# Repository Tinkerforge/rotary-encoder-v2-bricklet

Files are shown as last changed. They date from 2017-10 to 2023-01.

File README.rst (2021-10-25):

Rotary Encoder Bricklet 2.0
===========================

This repository contains the firmware source code and the hardware design
files. The documentation generator configs can be found at
https://github.com/Tinkerforge/generators

Repository Content
------------------

software/:
 * examples/: Examples for all supported languages
 * build/: Compiled files
 * src/: Source code of firmware
 * Makefile: Makefile to build project

hardware/:
 * Contains KiCad project files and additionally schematics as PDF

datasheets/:
 * Contains datasheets for sensors and complex ICs that are used

Hardware
--------

The hardware is designed with the open source EDA Suite KiCad
(http://www.kicad.org). Before you are able to open the files,
you have to install the Tinkerforge kicad-libraries
(https://github.com/Tinkerforge/kicad-libraries). You can either clone
them directly in hardware/ or clone them in a separate folder and
symlink them into hardware/
(ln -s kicad_path/kicad-libraries project_path/hardware). After that you
can open the .pro file in hardware/ with KiCad and from there view and
modify the schematics and the PCB layout.

Software
--------

If you want to do your own Brick/Bricklet firmware development we highly
recommend that you use our build environment setup script and read the
tutorial (https://www.tinkerforge.com/en/doc/Tutorials/Tutorial_Build_Environment/Tutorial.html).

To compile the C code we recommend you to install the newest GNU Arm Embedded
Toolchain (https://launchpad.net/gcc-arm-embedded/+download).
You also need to install bricklib2 (https://github.com/Tinkerforge/bricklib2).

You can either clone it directly in software/src/ or clone it in a
separate folder and symlink it into software/src/
(ln -s bricklib_path/bricklib2 project_path/software/src/). Finally make sure to
have CMake installed (http://www.cmake.org/cmake/resources/software.html).

After that you can build the firmware by invoking make in software/.
The firmware (.zbin) can then be found in software/build/ and uploaded
with brickv (click button "Flashing" on start screen).

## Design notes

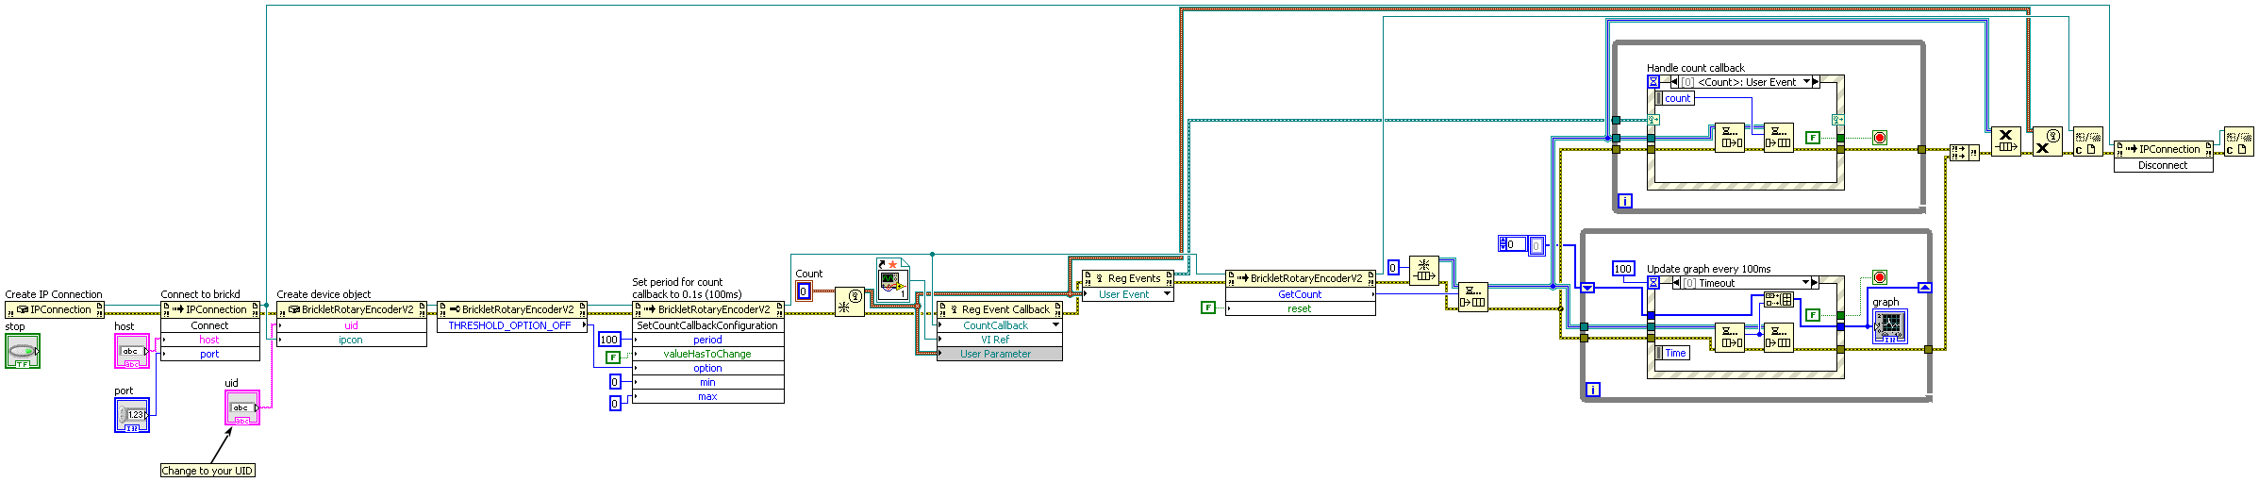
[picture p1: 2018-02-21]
software/examples/labview/Example Graph.vi.png

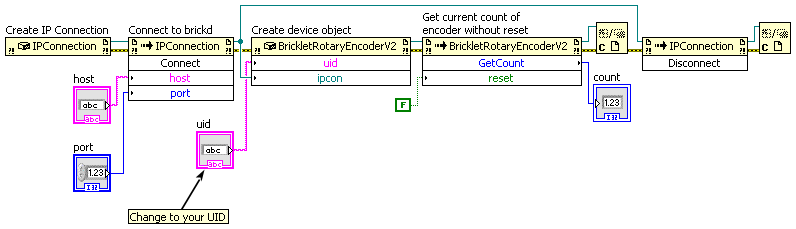
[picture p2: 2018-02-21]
software/examples/labview/Example Simple.vi.png

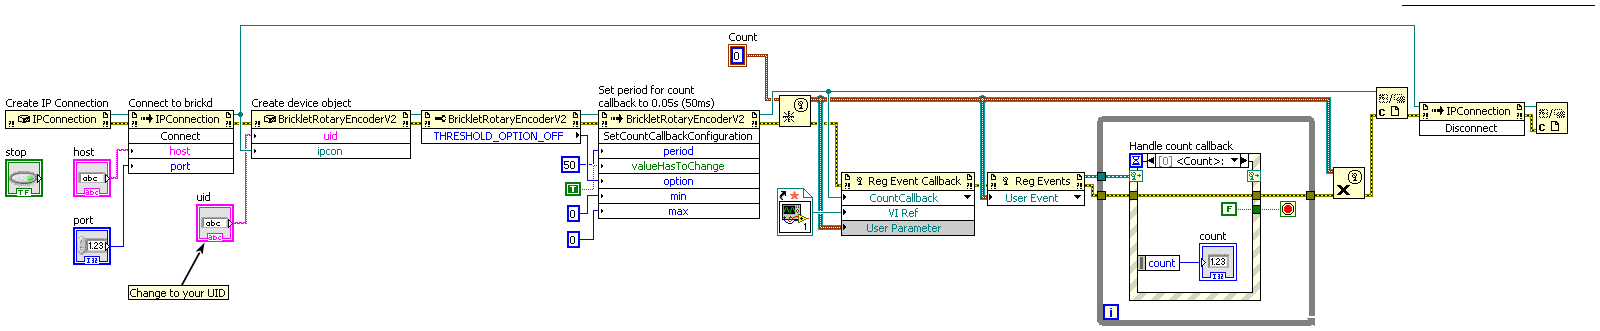
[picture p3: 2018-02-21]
software/examples/labview/Example Callback.vi.png

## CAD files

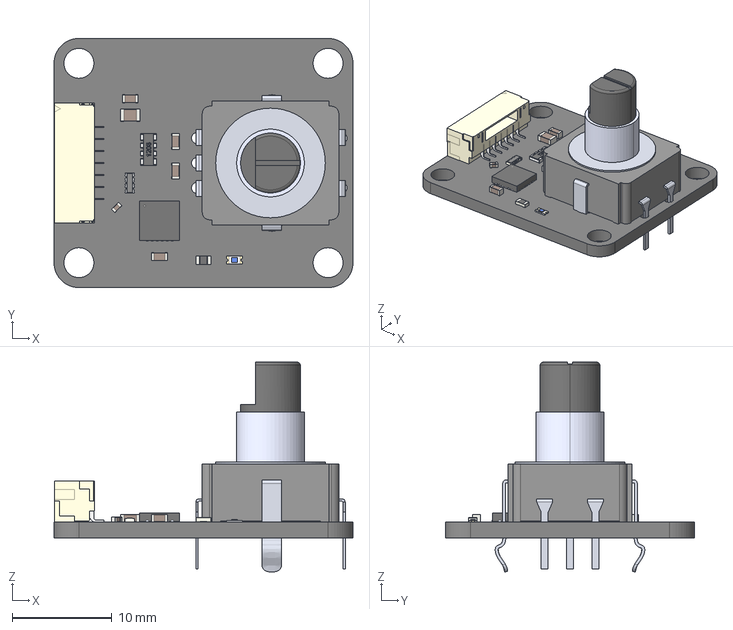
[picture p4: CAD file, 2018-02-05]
hardware/rotary-encoder-v2.step
30.0 x 25.0 x 21.0 mm

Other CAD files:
hardware/rotary-encoder-v2.FCStd

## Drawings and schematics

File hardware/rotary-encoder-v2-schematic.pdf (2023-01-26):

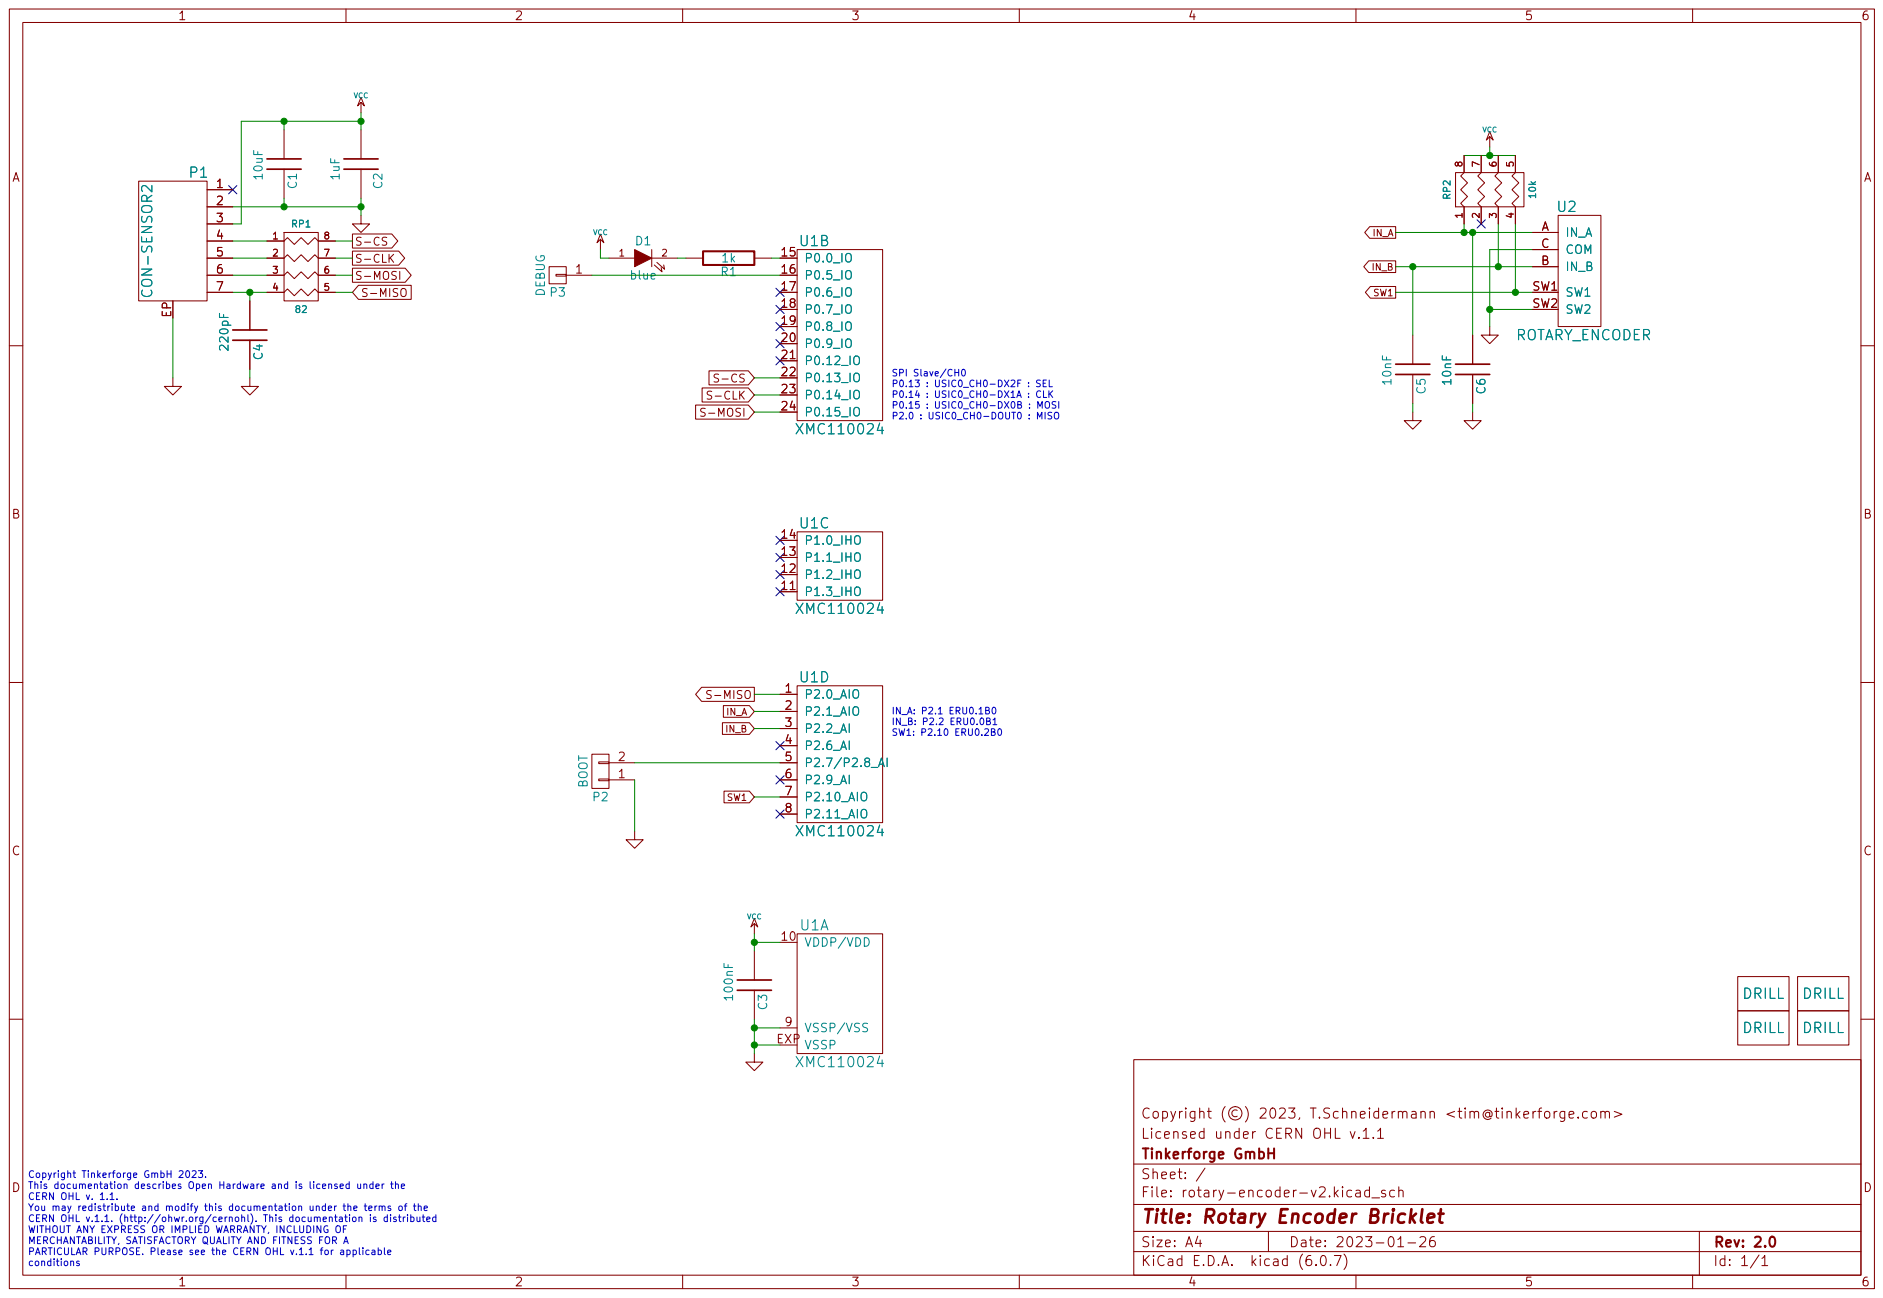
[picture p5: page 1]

SPI Slave/CH0 P0.13 : USIC0_CH0-DX2F : SEL P0.14 : USIC0_CH0-DX1A : CLK

IN_B: P2.2 ERU0.0B1 SW1: P2.10 ERU0.2B0 Copyright Tinkerforge GmbH 2023. This documentation describes Open Hardware and is licensed under the CERN OHL v. 1.1. You may redistribute and modify this documentation under the terms of the CERN OHL v.1.1. (http://ohwr.org/cernohl). This documentation is distributed WITHOUT ANY EXPRESS OR IMPLIED WARRANTY, INCLUDING OF MERCHANTABILITY, SATISFACTORY QUALITY AND FITNESS FOR A

Licensed under CERN OHL v.1.1
File: rotary-encoder-v2.kicad_sch Sheet: / Tinkerforge GmbH

Id: 1/1 Title: Rotary Encoder Bricklet

PARTICULAR PURPOSE. Please see the CERN OHL v.1.1 for applicable
conditions

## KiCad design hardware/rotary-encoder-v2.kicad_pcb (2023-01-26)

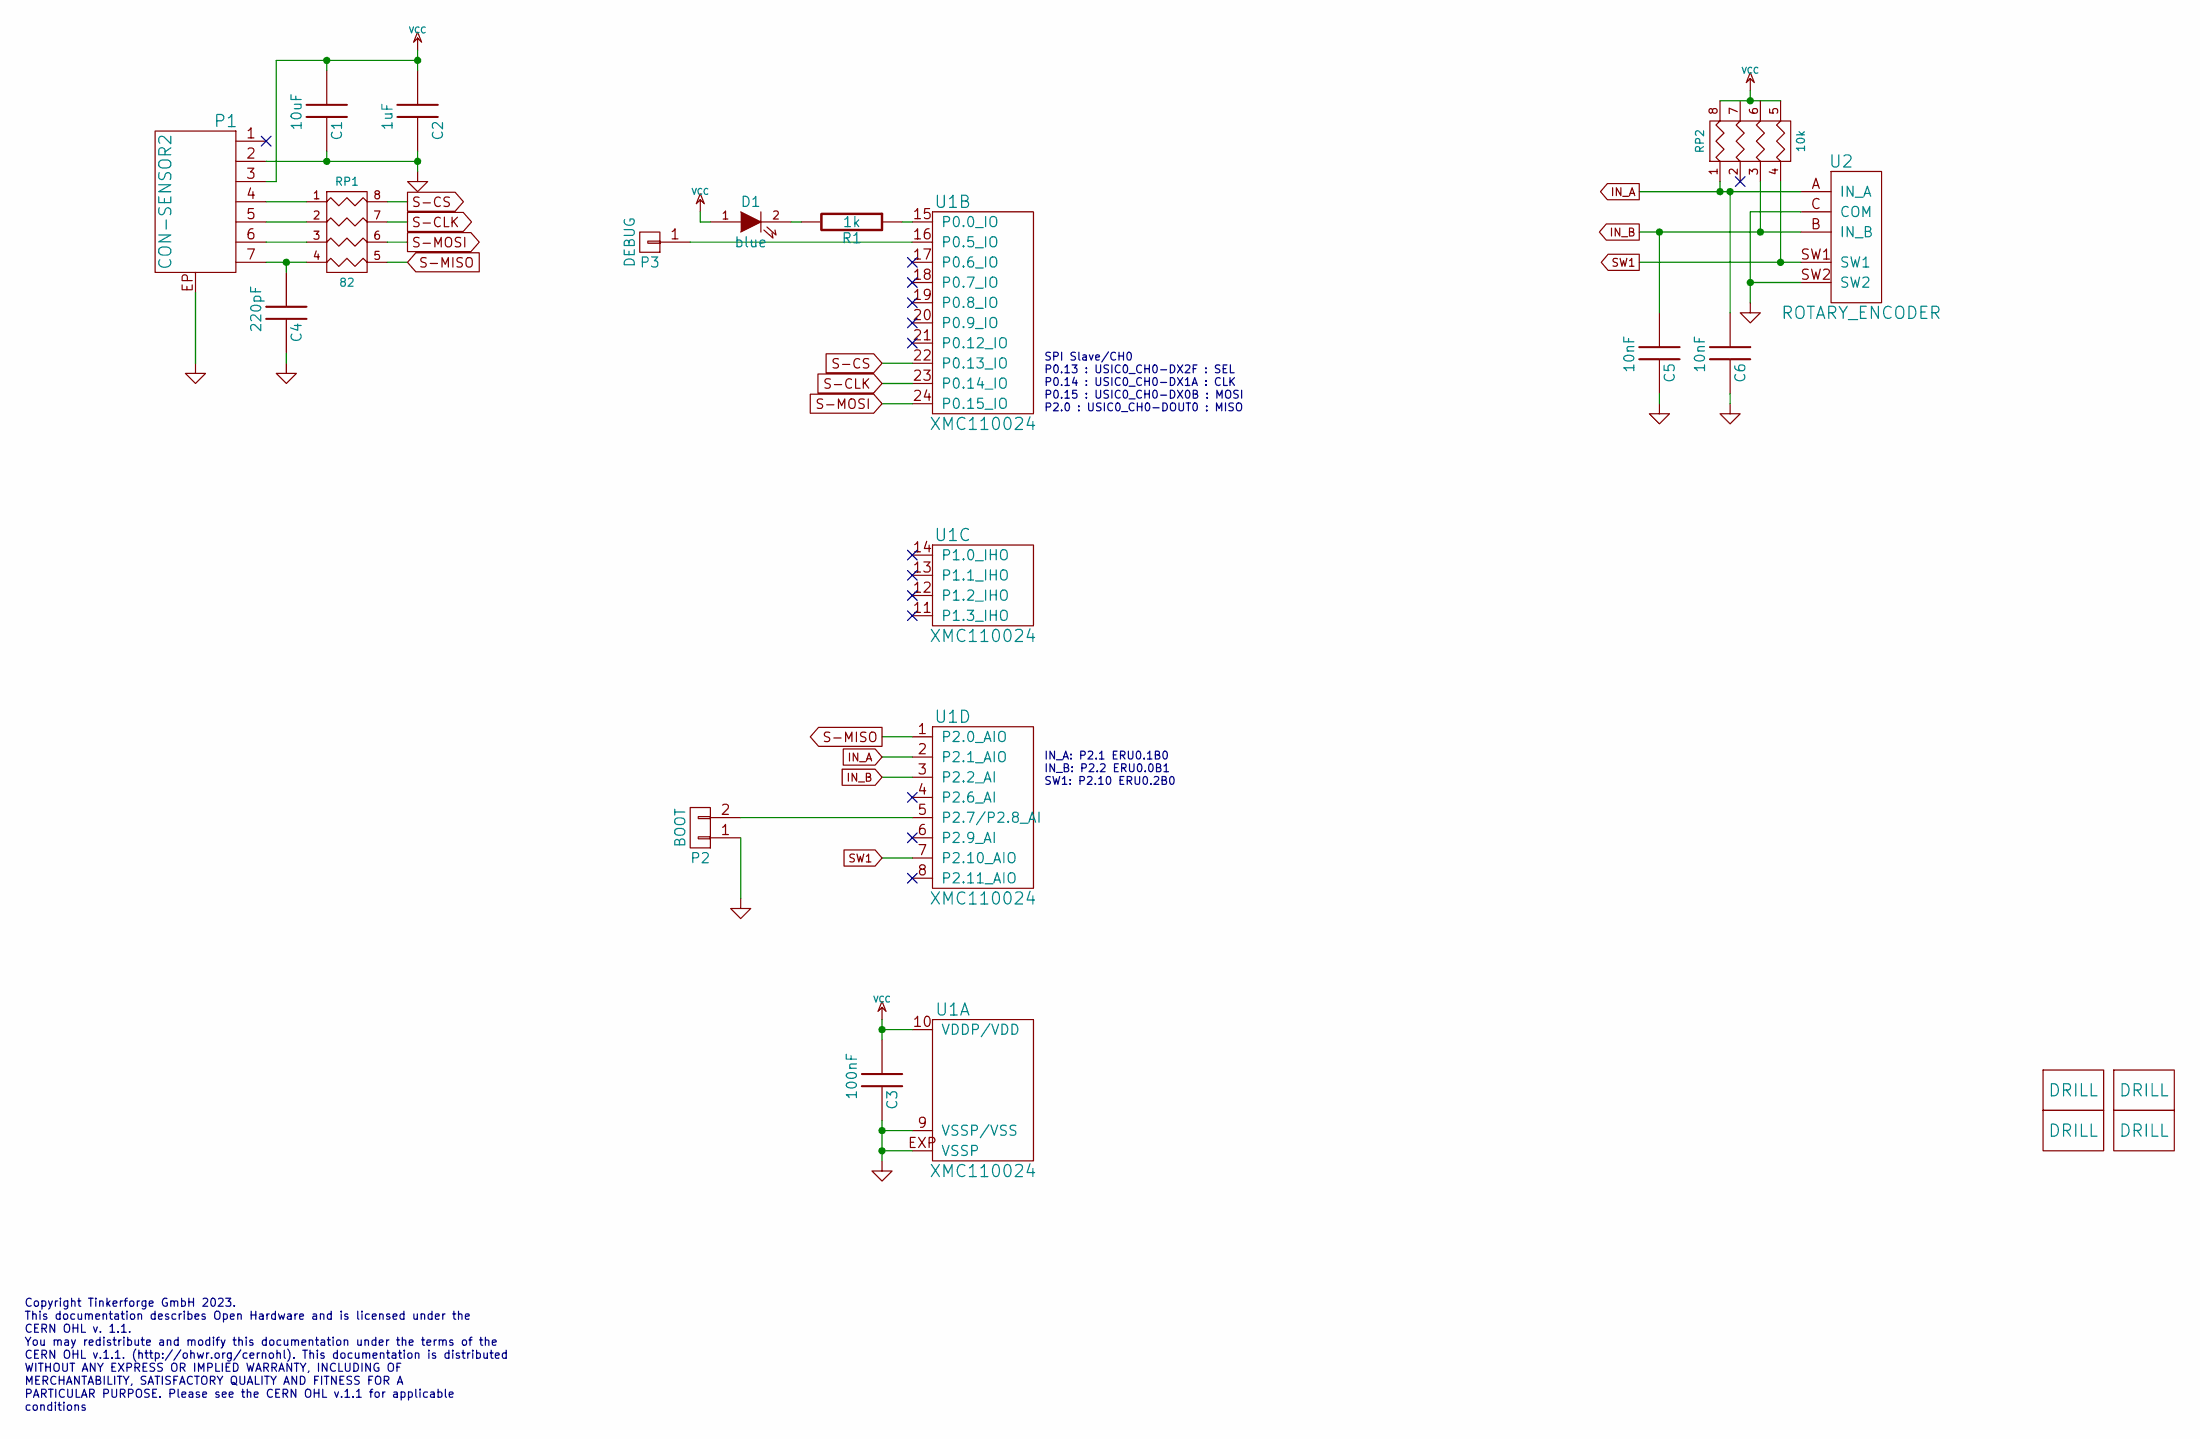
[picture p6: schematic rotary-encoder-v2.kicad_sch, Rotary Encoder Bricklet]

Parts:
C1: 10uF; C0805E
C2: 1uF; C0603F
C3: 100nF; C0603F
C4: 220pF; C0402F
C5, C6: 10nF; C0603F
D1: blue; D0603F
P1: CON-SENSOR2
P2: BOOT; SolderJumper
P3: DEBUG; DEBUG_PAD
R1: 1k; R0603F
RP1: 82; 4X0402
RP2: 10k; 4X0603
U1: XMC110024; QFN24-4x4mm-0.5mm
U2: ROTARY_ENCODER
U3, U4, U5, U6: DRILL; DRILL_NP

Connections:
GND: C1.2, C2.2, C3.2, C4.2, C5.2, C6.2, P1.2, P1.EP, P2.1, U1.9 (VSSP/VSS), U1.EXP (VSSP), U2.C (COM), U2.SW2
IN_A: C6.1, RP2.1, U1.2 (P2.1_AIO), U2.A (IN_A)
IN_B: C5.1, RP2.3, U1.3 (P2.2_AI), U2.B (IN_B)
unnamed: C4.1, P1.7, RP1.4
unnamed: D1.2 (K), R1.2
unnamed: P1.4, RP1.1
unnamed: P1.5, RP1.2
unnamed: P1.6, RP1.3
unnamed: P2.2, U1.5 (P2.7/P2.8_AI)
unnamed: P3.1, U1.16 (P0.5_IO)
unnamed: R1.1, U1.15 (P0.0_IO)
S-CLK: RP1.7 (R2), U1.23 (P0.14_IO)
S-CS: RP1.8 (R1), U1.22 (P0.13_IO)
S-MISO: RP1.5 (R4), U1.1 (P2.0_AIO)
S-MOSI: RP1.6 (R3), U1.24 (P0.15_IO)
SW1: RP2.4, U1.7 (P2.10_AIO), U2.SW1
VCC: C1.1, C2.1, C3.1, D1.1 (A), P1.3, RP2.5 (R4), RP2.6 (R3), RP2.7 (R2), RP2.8 (R1), U1.10 (VDDP/VDD)

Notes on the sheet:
IN_A: P2.1 ERU0.1B0 IN_B: P2.2 ERU0.0B1 SW1: P2.10 ERU0.2B0
Copyright Tinkerforge GmbH 2023. This documentation describes Open Hardware and is licensed under the CERN OHL v. 1.1. You may redistribute and modify this documentation under the terms of the CERN OHL v.1.1. (http://ohwr.org/cernohl). This documentation is distributed WITHOUT ANY EXPRESS OR IMPLIE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
SPI Slave/CH0 P0.13 : USIC0_CH0-DX2F : SEL P0.14 : USIC0_CH0-DX1A : CLK P0.15 : USIC0_CH0-DX0B : MOSI P2.0 : USIC0_CH0-DOUT0 : MISO

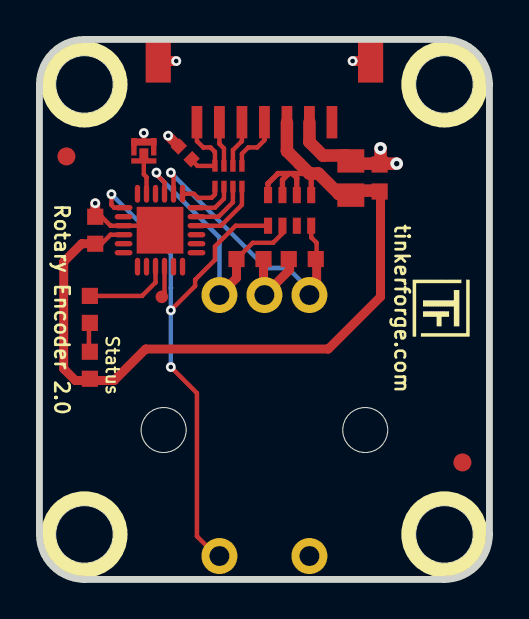
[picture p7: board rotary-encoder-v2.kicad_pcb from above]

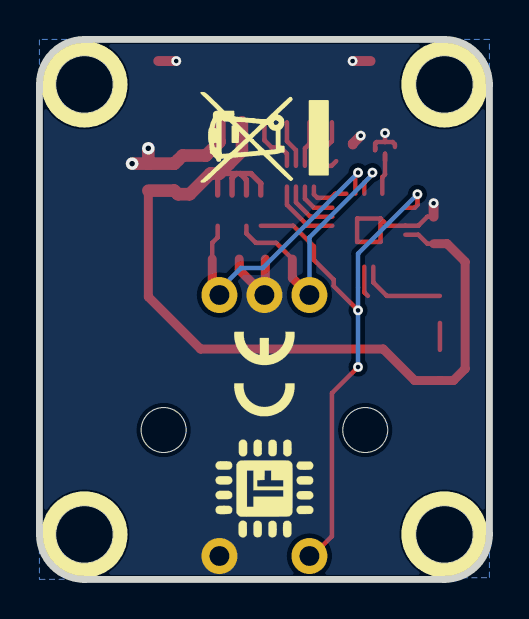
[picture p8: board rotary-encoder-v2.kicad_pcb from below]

Board: 2 copper layers, 25.0 x 30.0 mm, 23 parts (2 on the bottom side), 17 nets.

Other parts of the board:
Fiducial_Mark: VAL**; Fiducial_Mark
Fiducial_Mark#2: VAL**; Fiducial_Mark
VAL: WEEE_7mm
VAL#2: CE_5mm

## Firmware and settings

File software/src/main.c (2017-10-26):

/* rotary-encoder-v2-bricklet
 * Copyright (C) 2017 Olaf Lüke <olaf@tinkerforge.com>
 *
 * main.c: Initialization for Rotary Encoder V2 Bricklet
 *
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
 * You should have received a copy of the GNU Lesser General Public
 * License along with this library; if not, write to the
 * Free Software Foundation, Inc., 59 Temple Place - Suite 330,
 * Boston, MA 02111-1307, USA.
 */

#include <stdio.h>
#include <stdbool.h>

#include "configs/config.h"

#include "bricklib2/bootloader/bootloader.h"
#include "bricklib2/hal/system_timer/system_timer.h"
#include "bricklib2/logging/logging.h"
#include "communication.h"
#include "encoder.h"

int main(void) {
	logging_init();
	logd("Start Rotary Encoder V2 Bricklet\n\r");

	communication_init();
	encoder_init();

	while(true) {
		bootloader_tick();
		communication_tick();
		encoder_tick();
	}
}

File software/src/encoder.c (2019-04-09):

/* rotary-encoder-v2-bricklet
 * Copyright (C) 2017 Olaf Lüke <olaf@tinkerforge.com>
 *
 * encoder.c: Driver for rotary encoder
 *
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
 * You should have received a copy of the GNU Lesser General Public
 * License along with this library; if not, write to the
 * Free Software Foundation, Inc., 59 Temple Place - Suite 330,
 * Boston, MA 02111-1307, USA.
 */

#include "encoder.h"

#include <string.h>

#include "bricklib2/hal/system_timer/system_timer.h"

#include "configs/config.h"
#include "configs/config_encoder.h"

#include "xmc_eru.h"
#include "xmc_gpio.h"
#include "xmc_ccu4.h"

#define encoder_debounce_a_handler IRQ_Hdlr_21
#define encoder_debounce_b_handler IRQ_Hdlr_22

#define encoder_a_handler IRQ_Hdlr_4
#define encoder_b_handler IRQ_Hdlr_3

const int8_t encoder_table[4][4] = {
    { 0,  1, -1,  0},
    {-1,  0,  0,  1},
    { 1,  0,  0, -1},
    { 0, -1,  1,  0}
};

Encoder encoder;

static int32_t encoder_count = 0;
static int8_t encoder_last_value = 0;

// We do the actual measurements in the debounce handler.
// The handler is called 100us after we see a edge change.
// This way we make sure that we never take a value during the initial bounciness after the edge changes.
// If the pot is turned at "maximum human speed" the edges chage about every 500us, so with 100us debounce
// we still have a big margin of error.
void __attribute__((optimize("-O3"))) __attribute__ ((section (".ram_code"))) encoder_debounce_a_handler(void) {
	NVIC_ClearPendingIRQ(ENCODER_A_IRQ_N);
	NVIC_EnableIRQ(ENCODER_A_IRQ_N);

	const uint8_t encoder_value = XMC_GPIO_GetInput(ENCODER_A_PIN) | (XMC_GPIO_GetInput(ENCODER_B_PIN) << 1);

	int8_t add = encoder_table[encoder_last_value][encoder_value];
	encoder_count += add;
	encoder_last_value = encoder_value;
}

void __attribute__((optimize("-O3"))) __attribute__ ((section (".ram_code"))) encoder_debounce_b_handler(void) {
	NVIC_ClearPendingIRQ(ENCODER_B_IRQ_N);
	NVIC_EnableIRQ(ENCODER_B_IRQ_N);

	const uint8_t encoder_value = XMC_GPIO_GetInput(ENCODER_A_PIN) | (XMC_GPIO_GetInput(ENCODER_B_PIN) << 1);

	int8_t add = encoder_table[encoder_last_value][encoder_value];
	encoder_count += add;
	encoder_last_value = encoder_value;
}


void __attribute__((optimize("-O3"))) __attribute__ ((section (".ram_code"))) encoder_a_handler(void) {
	CCU40_CC40->TCCLR = CCU4_CC4_TCCLR_TCC_Msk;
	CCU40_CC40->TCSET = CCU4_CC4_TCSET_TRBS_Msk;
	NVIC_DisableIRQ(ENCODER_A_IRQ_N);
}

void __attribute__((optimize("-O3"))) __attribute__ ((section (".ram_code"))) encoder_b_handler(void) {
	CCU40_CC41->TCCLR = CCU4_CC4_TCCLR_TCC_Msk;
	CCU40_CC41->TCSET = CCU4_CC4_TCSET_TRBS_Msk;
	NVIC_DisableIRQ(ENCODER_B_IRQ_N);
}

void encoder_init_debounce_timer(void) {
	XMC_CCU4_SLICE_COMPARE_CONFIG_t timer_config = {
		.timer_mode          = XMC_CCU4_SLICE_TIMER_COUNT_MODE_EA,
		.monoshot            = XMC_CCU4_SLICE_TIMER_REPEAT_MODE_SINGLE,
		.shadow_xfer_clear   = false,
		.dither_timer_period = false,
		.dither_duty_cycle   = false,
		.prescaler_mode      = XMC_CCU4_SLICE_PRESCALER_MODE_NORMAL,
		.mcm_enable          = false,
		.prescaler_initval   = XMC_CCU4_SLICE_PRESCALER_64, // Use prescaler 64 to get 1 tick = 1us
		.float_limit         = 0U,
		.dither_limit        = 0U,
		.passive_level       = XMC_CCU4_SLICE_OUTPUT_PASSIVE_LEVEL_LOW,
		.timer_concatenation = false
	};

    XMC_CCU4_Init(CCU40, XMC_CCU4_SLICE_MCMS_ACTION_TRANSFER_PR_CR);
    XMC_CCU4_StartPrescaler(CCU40);


	// Timer input A
    XMC_CCU4_EnableClock(CCU40, 0);
    XMC_CCU4_SLICE_CompareInit(CCU40_CC40, &timer_config);
    XMC_CCU4_SLICE_SetTimerPeriodMatch(CCU40_CC40, ENCODER_DEBOUNCE_TIME);
    XMC_CCU4_SLICE_SetTimerCompareMatch(CCU40_CC40, 0);
    XMC_CCU4_EnableShadowTransfer(CCU40, XMC_CCU4_SHADOW_TRANSFER_SLICE_0 | XMC_CCU4_SHADOW_TRANSFER_PRESCALER_SLICE_0);

    XMC_CCU4_SLICE_EnableEvent(CCU40_CC40, XMC_CCU4_SLICE_IRQ_ID_PERIOD_MATCH);
	XMC_CCU4_SLICE_SetInterruptNode(CCU40_CC40, XMC_CCU4_SLICE_IRQ_ID_PERIOD_MATCH, XMC_CCU4_SLICE_SR_ID_0);
	NVIC_EnableIRQ(CCU40_0_IRQn);
	NVIC_SetPriority(CCU40_0_IRQn, ENCODER_DEBOUNCE_PRIO);


	// Timer input B
    XMC_CCU4_EnableClock(CCU40, 1);
    XMC_CCU4_SLICE_CompareInit(CCU40_CC41, &timer_config);
    XMC_CCU4_SLICE_SetTimerPeriodMatch(CCU40_CC41, ENCODER_DEBOUNCE_TIME);
    XMC_CCU4_SLICE_SetTimerCompareMatch(CCU40_CC41, 0);
    XMC_CCU4_EnableShadowTransfer(CCU40, XMC_CCU4_SHADOW_TRANSFER_SLICE_1 | XMC_CCU4_SHADOW_TRANSFER_PRESCALER_SLICE_1);

    XMC_CCU4_SLICE_EnableEvent(CCU40_CC41, XMC_CCU4_SLICE_IRQ_ID_PERIOD_MATCH);
	XMC_CCU4_SLICE_SetInterruptNode(CCU40_CC41, XMC_CCU4_SLICE_IRQ_ID_PERIOD_MATCH, XMC_CCU4_SLICE_SR_ID_1);
	NVIC_EnableIRQ(CCU40_1_IRQn);
	NVIC_SetPriority(CCU40_1_IRQn, ENCODER_DEBOUNCE_PRIO);
}

void encoder_init_eru(void) {
	// A config (ERU0.1B0)
	const XMC_ERU_ETL_CONFIG_t a_etl_config = {
		.input_a                = XMC_ERU_ETL_INPUT_A0,
		.input_b                = XMC_ERU_ETL_INPUT_B0,
		.enable_output_trigger  = 1,
		.edge_detection         = XMC_ERU_ETL_EDGE_DETECTION_BOTH,
		.output_trigger_channel = XMC_ERU_ETL_OUTPUT_TRIGGER_CHANNEL1, // Select the source for event
		.source                 = XMC_ERU_ETL_SOURCE_B
	};

	// ERU Event Trigger Logic Hardware initialization based on UI
	XMC_ERU_ETL_Init(XMC_ERU0, ENCODER_A_ETL_CHANNEL, &a_etl_config);
	// OGU is configured to generate event on configured trigger edge
	XMC_ERU_OGU_SetServiceRequestMode(XMC_ERU0, ENCODER_A_OGU_CHANNEL, XMC_ERU_OGU_SERVICE_REQUEST_ON_TRIGGER);
	// Configure NVIC node and priority
	NVIC_SetPriority(ENCODER_A_IRQ_N, ENCODER_A_IRQ_PRIO);

	// Clear pending interrupt before enabling it
	NVIC_ClearPendingIRQ(ENCODER_A_IRQ_N);
	// Enable NVIC node
	NVIC_EnableIRQ(ENCODER_A_IRQ_N);


	// B config (ERU0.0B1)
	const XMC_ERU_ETL_CONFIG_t b_etl_config = {
		.input_a                = XMC_ERU_ETL_INPUT_A0,
		.input_b                = XMC_ERU_ETL_INPUT_B1,
		.enable_output_trigger  = 1,
		.edge_detection         = XMC_ERU_ETL_EDGE_DETECTION_BOTH,
		.output_trigger_channel = XMC_ERU_ETL_OUTPUT_TRIGGER_CHANNEL0, // Select the source for event
		.source                 = XMC_ERU_ETL_SOURCE_B
	};

	// ERU Event Trigger Logic Hardware initialization based on UI
	XMC_ERU_ETL_Init(XMC_ERU0, ENCODER_B_ETL_CHANNEL, &b_etl_config);
	// OGU is configured to generate event on configured trigger edge
	XMC_ERU_OGU_SetServiceRequestMode(XMC_ERU0, ENCODER_B_OGU_CHANNEL, XMC_ERU_OGU_SERVICE_REQUEST_ON_TRIGGER);
	// Configure NVIC node and priority
	NVIC_SetPriority(ENCODER_B_IRQ_N, ENCODER_B_IRQ_PRIO);

	// Clear pending interrupt before enabling it
	NVIC_ClearPendingIRQ(ENCODER_B_IRQ_N);
	// Enable NVIC node
	NVIC_EnableIRQ(ENCODER_B_IRQ_N);
}
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

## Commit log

2017-09-15 Add schematic
    [rotary_encoder.sch]
2017-09-18 Change pins
    [rotary_encoder.sch]
2017-09-18 Add PCB
    [rotary_encoder.kicad_pcb]
2017-09-18 Finished prototype
    [rotary_encoder.kicad_pcb]
2017-09-18 Add logos
    [rotary_encoder.kicad_pcb]
2017-10-13 Add initial stub implementation
    [cmake_config_custom.txt]
2017-10-18 change led position
    [rotary_encoder.kicad_pcb]
2017-10-25 fix debug pin connection
    [rotary_encoder.kicad_pcb, rotary_encoder.sch]
2017-10-25 add rc capacitors, mode debug
    * add two 10nF capacitors to a,b to remove glitches
    * move debug pin
    [rotary_encoder.kicad_pcb, rotary_encoder.sch]
2017-10-26 Add minimal encoder count implementation
2017-10-26 specify processor type
    [rotary_encoder.kicad_pcb, rotary_encoder.sch]
2018-02-05 Add 3d information (final)
    [rotary_encoder.kicad_pcb]
2018-02-05 Add 3d model (*.step & *.FCStd)
    [rotary_encoder.FCStd, rotary_encoder.step]
2018-02-16 Add schematic (PDF)
    [rotary_encoder.sch]
2018-02-19 add cutout information
    [rotary_encoder.kicad_pcb]
2018-02-20 Cleanup KiCad libraries config
    Ensure LibDir=kicad-libraries and LibName1=tinkerforge.
    Remove special library.
2018-05-11 Rename files
    [rotary-encoder-v2.FCStd, rotary-encoder-v2.kicad_pcb, rotary-encoder-v2.sch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]
2018-06-06 Adapt to bricklib2 callback-value changes to fix wrong threshold min/max type
    It was uint16_t but is should have always been int32_t. This changes the
    packet size of the threshold config functions.
    [communication.c]
2018-06-18 Change capacitor footprint(s) to C0402F
    [rotary-encoder-v2.kicad_pcb, rotary-encoder-v2.sch]
2019-01-18 drc, fix status text
    [rotary-encoder-v2.kicad_pcb]
2019-04-09 Fix bug in reset count logic
    [encoder.c]
2019-05-29 Disallow SPITFP interrupt to disable IRQs
    The newest version of bricklib2 disables IRQs during SPITFP
    transfers by default. This needs to be turned off for this
    Bricklet since it has higher priority IRQs that can not wait.
    For this we set the SPITFP_NOT_ALLOWED_TO_DISABLE_IRQ define.
2019-08-22 c: Adapt to bindings changes
    [example_callback.c]
2020-08-31 uc: Use fixed-with placeholders in format strings.
    [example_callback.c, example_simple.c]
2020-09-02 uc: Add example driver note.
2021-10-25 Update KiCad link
    https://www.kicad.org/blog/2021/10/Avoid-links-to-former-kicad-domain/
2022-04-27 uc: Adapt to bindings changes
    [example_callback.c, example_simple.c]
2023-01-23 New standart layout. Switched to Kicad 6
    [rotary-encoder-v2.kicad_pcb, rotary-encoder-v2.kicad_sch, rotary-encoder-v2.sch]
2023-01-26 fix symbol libraries
    [rotary-encoder-v2.kicad_sch]
2023-01-26 Data Cleanup
    [rotary-encoder-v2.kicad_pcb, rotary-encoder-v2.kicad_sch]

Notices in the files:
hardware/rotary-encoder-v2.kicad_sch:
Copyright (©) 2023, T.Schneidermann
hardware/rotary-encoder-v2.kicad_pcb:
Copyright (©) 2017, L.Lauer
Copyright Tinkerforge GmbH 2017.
